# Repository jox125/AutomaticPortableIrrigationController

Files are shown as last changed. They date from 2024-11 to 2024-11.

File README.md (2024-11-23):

# Automatic Portable Irrigation System

This automatic watering system was developed and manufactured as my final thesis in Mechatronics at the Võru County Vocational Education Center.
In this repository you find two main parts: 
1. Water distribution system hardware overview
2. Controller software

All parts are placed in a common housing to ensure easy installation and transportation of the system.
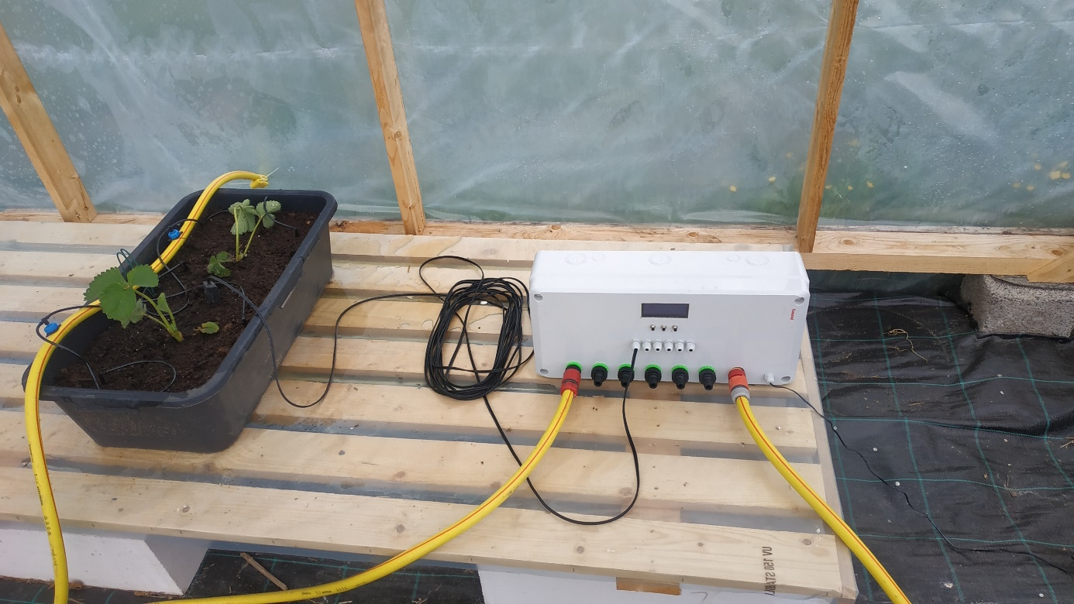
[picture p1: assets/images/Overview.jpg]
Overview of the system in testing

You can find additional information in my thesis in [here](/assets/Joel_Lepp_Thesis_est.docx)

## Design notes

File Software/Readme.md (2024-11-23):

This software is made for Arduino Mega 2560. 
This board was chosen with the possibility of adding future features in mind.

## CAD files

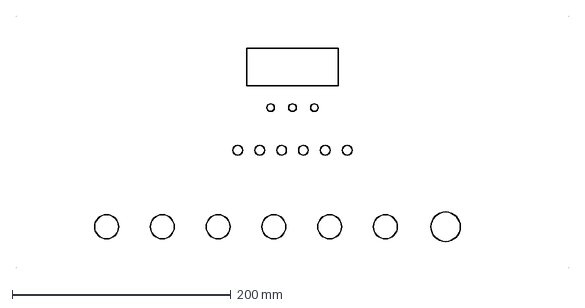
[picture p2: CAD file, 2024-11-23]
Hardware/Front panel.dxf
505.2 x 230.2 mm

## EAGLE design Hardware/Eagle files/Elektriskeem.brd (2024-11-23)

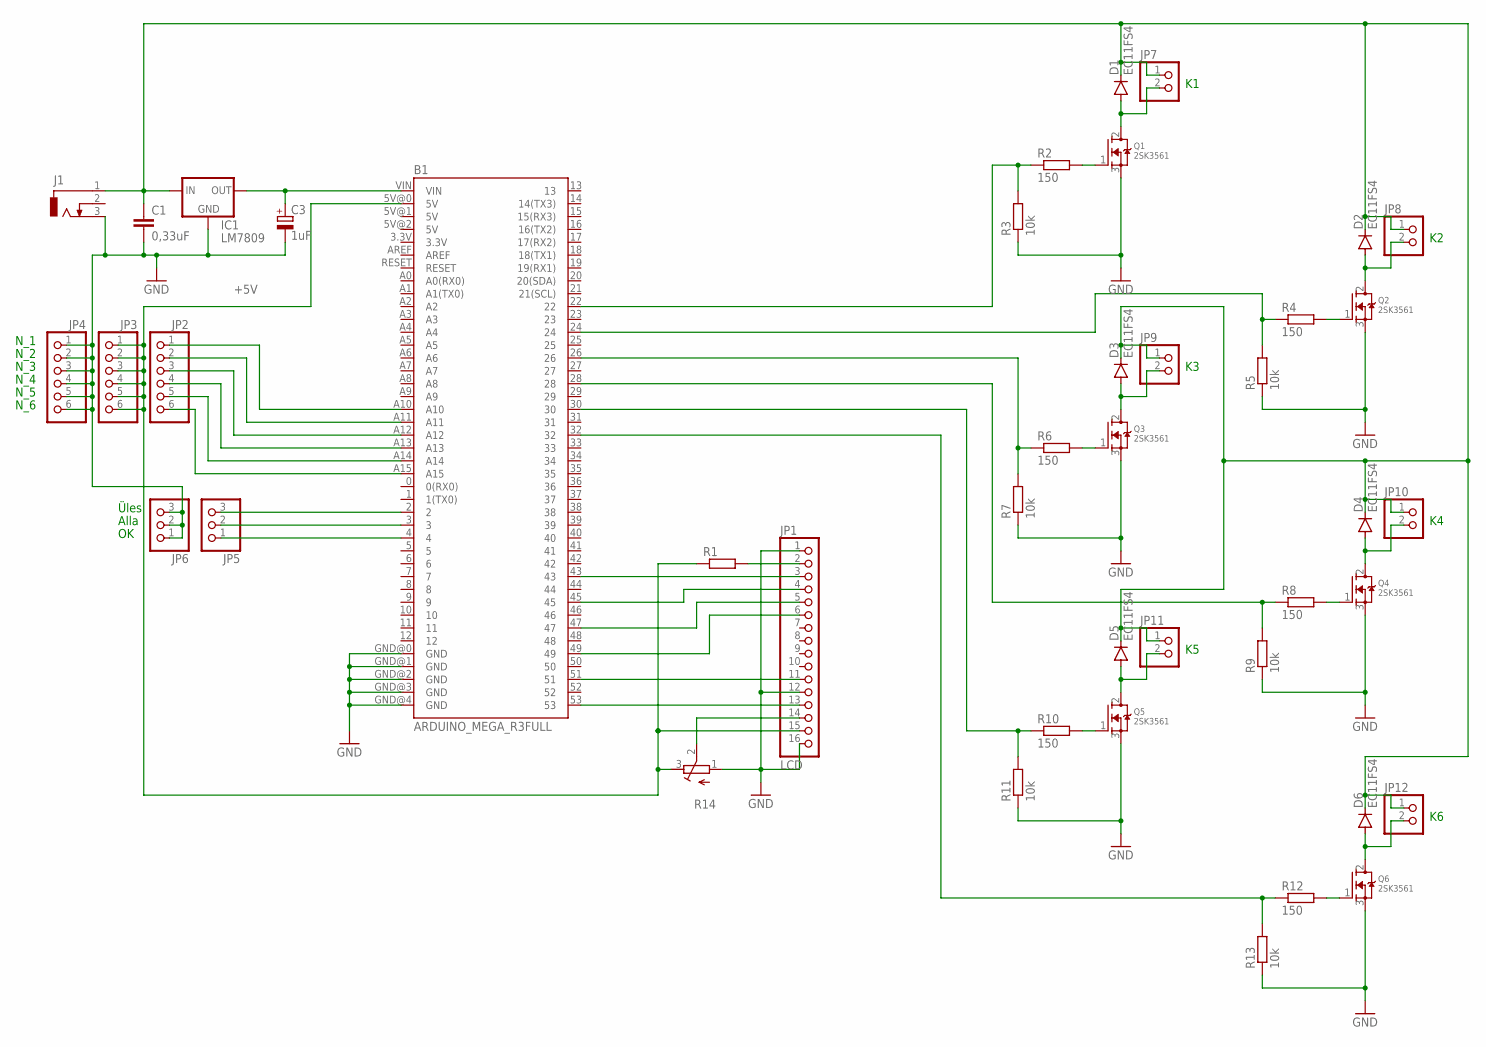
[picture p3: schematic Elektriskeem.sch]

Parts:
B1: ARDUINO_MEGA_R3FULL; ARDUINO_MEGA
C1: 0,33uF; C102-043X133
C3: 1uF; E2,5-6
D1, D2, D3, D4, D5, D6: EC11FS4; DO214AA
IC1: LM7809; 78XXS
J1: DCJ0303
JP1: LCD; 1X16
JP2, JP3, JP4: PINHD-1X6; 1X06
JP5, JP6: PINHD-1X3; 1X03
JP7, JP8, JP9, JP10, JP11, JP12: PINHD-1X2; 1X02
Q1, Q2, Q3, Q4, Q5, Q6: 2SK3561; TO220V
R1: R-EU_0207/12; 0207/12
R2, R4, R6, R8, R10, R12: 150; 0207/12
R3, R5, R7, R9, R11, R13: 10k; 0207/12
R14: R-TRIMM3339P; RTRIM3339P

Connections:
+5V: B1.5V@0 (5V), JP1.15, JP3.1, JP3.2, JP3.3, JP3.4, JP3.5, JP3.6, R1.1, R14.3 (E)
GND: B1.GND@0 (GND), B1.GND@1 (GND), B1.GND@2 (GND), B1.GND@3 (GND), B1.GND@4 (GND), C1.2, C3.-, IC1.GND, J1.3, JP1.1, JP1.12, JP1.16, JP4.1, JP4.2, JP4.3, JP4.4, JP4.5, JP4.6, JP6.1, JP6.2, JP6.3, Q1.3 (S), Q2.3 (S), Q3.3 (S), Q4.3 (S), Q5.3 (S), Q6.3 (S), R3.1, R5.1, R7.1, R9.1, R11.1, R13.1, R14.1 (A)
unnamed: C1.1, D1.C, D2.C, D3.C, D4.C, D5.C, D6.C, IC1.IN, J1.1, JP7.1, JP8.1, JP9.1, JP10.1, JP11.1, JP12.1
unnamed: B1.2, JP5.3
unnamed: B1.VIN, C3.+, IC1.OUT
unnamed: B1.A15, JP2.6
unnamed: B1.26, R6.1, R7.2
unnamed: B1.A14, JP2.5
unnamed: B1.A13, JP2.4
unnamed: B1.A12, JP2.3
unnamed: B1.A11, JP2.2
unnamed: B1.A10, JP2.1
unnamed: B1.43, JP1.3
unnamed: B1.53, JP1.13
unnamed: JP1.2, R1.2
unnamed: JP1.14, R14.2 (S)
unnamed: B1.51, JP1.11
unnamed: B1.45, JP1.4
unnamed: B1.47, JP1.5
unnamed: B1.49, JP1.6
unnamed: B1.3, JP5.2
unnamed: B1.4, JP5.1
unnamed: Q1.1 (G), R2.2
unnamed: D1.A, JP7.2, Q1.2 (D)
unnamed: B1.22, R2.1, R3.2
unnamed: D3.A, JP9.2, Q3.2 (D)
unnamed: Q3.1 (G), R6.2
unnamed: D5.A, JP11.2, Q5.2 (D)
unnamed: Q5.1 (G), R10.2
unnamed: B1.30, R10.1, R11.2
unnamed: D2.A, JP8.2, Q2.2 (D)
unnamed: Q2.1 (G), R4.2
unnamed: B1.24, R4.1, R5.2
unnamed: D4.A, JP10.2, Q4.2 (D)
unnamed: Q4.1 (G), R8.2
unnamed: B1.28, R8.1, R9.2
unnamed: D6.A, JP12.2, Q6.2 (D)
unnamed: Q6.1 (G), R12.2
unnamed: B1.32, R12.1, R13.2

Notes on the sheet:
Üles
Alla
N_1
N_2
N_3
N_4
N_5
N_6

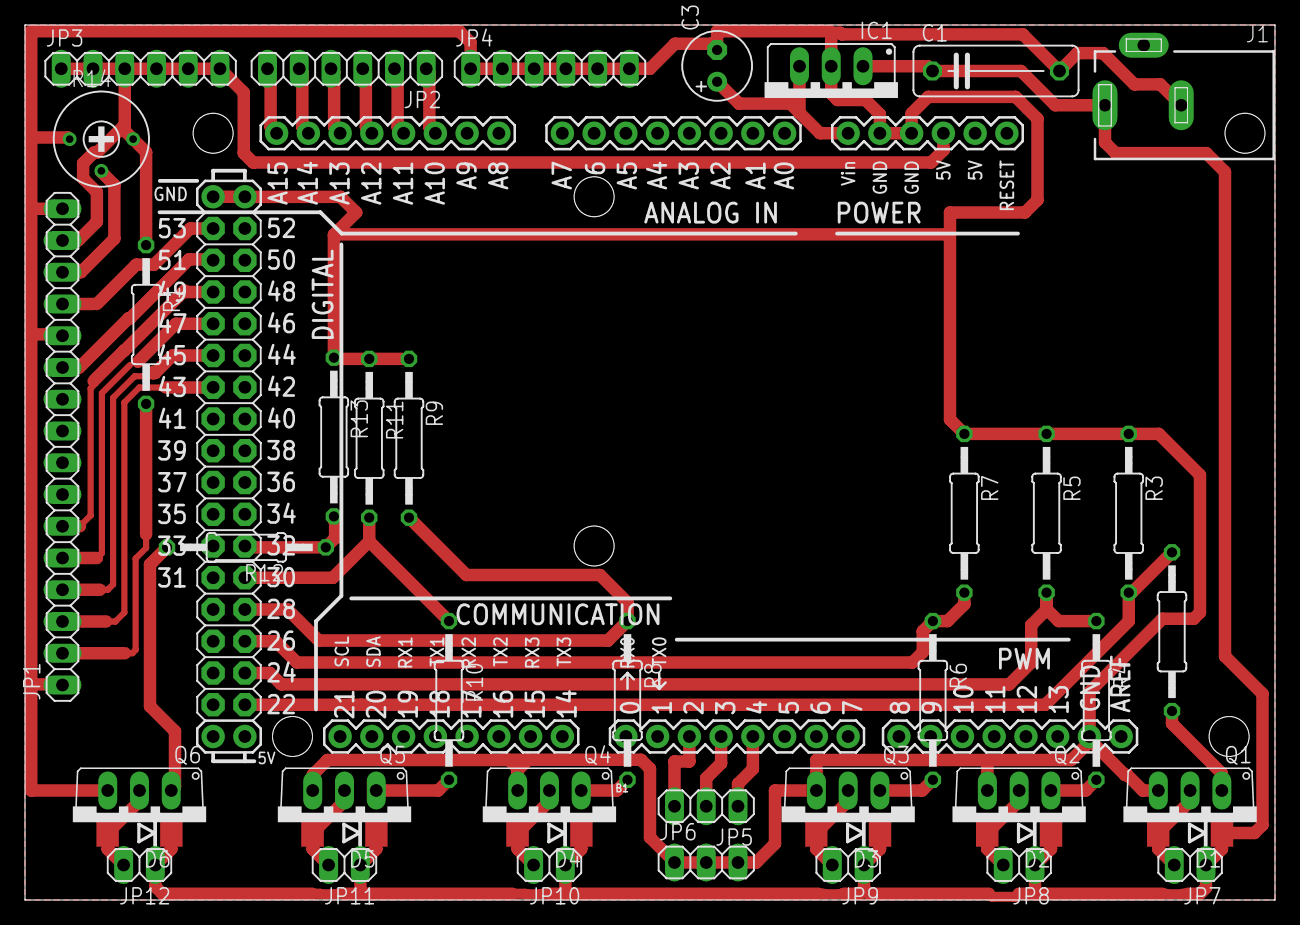
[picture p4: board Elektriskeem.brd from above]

Board: 2 copper layers, 100.0 x 70.0 mm, 43 parts (0 on the bottom side), 39 nets.

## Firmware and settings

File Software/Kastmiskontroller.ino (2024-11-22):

//*********************************************//
//*            LCD seadistus                  *//
//*********************************************//

//Lisa LCD teek.
#include <LiquidCrystal.h>

//seadista LiquidCrystal teek
const int rs = 53, en = 51, d4 = 49, d5 = 47, d6 = 45, d7 = 43;
LiquidCrystal lcd(rs, en, d4, d5, d6, d7);

//Ajaviideteks vajalikud muutujad
// Ekraani taimeri eelmine salvestatud aeg
unsigned long ekraan_eelmineMillis = 0;
// Ekraani värskendamise intervall millisekundites (sek x 1000)
unsigned long ekraan_intervall = 500; //0,5 sek

//*********************************************//
//*            Nuppude seadistus              *//
//*********************************************//

//Lisa Nuppude teek.
#include <Button.h>
//seadista nuppude pin-id.
Button ules_nupp(2); //üles nupp ühendatud D2 ja GND vahele
Button alla_nupp(3); //alla nupp ühendatud D3 ja GND vahele
Button ok_nupp(4);   //ok nupp ühendatud D4 ja GND vahele
//Ajaviideteks vajalikud muutujad
// Nuppude taimeri eelmine salvestatud aeg
unsigned long ules_nupp_eelmineMillis = 0;
unsigned long alla_nupp_eelmineMillis = 0;
// nuppuvajutuste intervall millisekundites (sek x 1000)
unsigned long nupud_intervall = 1000; //1 sek

int arv = 0;
bool alla_nupp_vajutatud = false;
bool ules_nupp_vajutatud = false;

//*********************************************//
//*    Globaalsete muutujate deklareerimine   *//
//*********************************************//

//Niiskuse mõõtmiseks vajalikud muutujad

//Mõõdetud niiskus 
int niiskused[6] = {100,100,100,100,100,100};
int min_niiskus = 910;
int max_niiskus = 510;
//Vajalikud analoog sisendid
int N_andur [6] = {10,11,12,13,14,15};  //Niiskuse andurite pin-id A10-A15 
//Ajaviideteks vajalikud muutujad
// Niiskuse taimeri eelmine salvestatud aeg
unsigned long niiskus_eelmineMillis = 0;
// Niiskuse mõõtmise intervall millisekundites (sek x 1000)
unsigned long niiskus_intervall = 10000; //10 sek

//Kastmise alamprogrammi muutujad

//toimub kastmine bit
bool toimub_kastmine [6] = {false, false, false, false, false, false}; 
//releede pin-ide määramine
int releed [6] = {22,24,26,28,30,32}; //releede pin-id D22 - D32
//mulla niiskuse protsent, millest kuivema mulla korral hakatakse kastma
//ja millest niiskema mulla korral lõpetatakse kastmine
int min_niiskus_s2te [6] = {0,0,0,0,0,0}; 
int max_niiskus_s2te [6] = {90,90,90,90,90,90}; 
//Ajaviideteks vajalikud muutujad
// Kastmise alamprogrammi taimeri eelmine salvestatud aeg
unsigned long kastmine_eelmineMillis = 0;
//kastmise alamprogrammi intervall millisekundites (sek x 1000)
unsigned long kastmine_intervall = 1000; //1 sek

//kontroll alamprogrammi globaalsed muutujad.
int aktiivne_ekraan = 0;
int grupp = 1; //hetkel aktiivne grupp, mille seadeid muudetakse

void setup() {
//setup käsud täidetakse üks kord arduino käivitumisel
//Serial.begin(9600);

//Seadista nupud
ules_nupp.begin(); //käivita üles nupp jälgimine 
alla_nupp.begin(); //käivita alla nupp jälgimine
ok_nupp.begin();   //käivita ok nupp jälgimine

//Seadista LCD sümbolite arv ja read
  lcd.begin(20, 4);
  // Print a message to the LCD.
  lcd.print("Kastmis kontroll");
  delay (2000);
  lcd.clear();

//releede pin-ide konfigureerimine
for (int a=0; a<6; a++){
  pinMode(releed [a], OUTPUT);
  }
}

void loop() {
  // Programmi tsükliline osa
niiskus ();
kastmine ();
kontroll ();
}


void niiskus (){
/*
 * Niiskuse mõõtmine. Mõõdab iga määratud T_niiskus (ms) järel
 * gruppide kaupa mulla niiskuse ja salvestab tulemuse niiskused massiivi. 
 */  
  unsigned long hetkeMillis = millis();
  //aja intervalli möödumise kontroll 
  if(hetkeMillis - niiskus_eelmineMillis > niiskus_intervall) {
    niiskus_eelmineMillis = hetkeMillis;
    //kõik grupid 
    //Serial.print("Mulla niiskused: ");  
    for (int i = 0; i<6; i++){
      //kümne mõõtmise keskmine
      int keskmine = 0;
      for (int e=0; e<10; e++){
        keskmine = keskmine + analogRead(N_andur[i]);
        }
      keskmine = keskmine / 10;
      //mõõdetud niiskuse salvestamine massiivi
      niiskused [i] = map(keskmine, min_niiskus, max_niiskus, 0, 100);
      //Serial.print(niiskused[i]);
      //Serial.print(" ; ");
      }
      //Serial.println();
    }
    
}
void kastmine (){
/*
 * Kui eelmisest programmi käivitamisest on möödunud piisavalt aega, siis 
 * gruppide kaupa kontrollib, kui kastmist ei toimu, siis kui niiskus on 
 * allpool määratud piiri, kastmine sisse, kastmine bit tõeseks.   
 * Kui kastmine toimub, siis kui muld on piisavalt märg
 * kastmine välja, kastmine bit vääraks.
 */
unsigned long hetkeMillis = millis();
  //aja intervalli möödumise kontroll 
  if (hetkeMillis - kastmine_eelmineMillis > kastmine_intervall) {
    kastmine_eelmineMillis = hetkeMillis;
    //kõik grupid 
    //Serial.print("Kastmised: ");  
    for (int i = 0; i<6; i++){
      if (!toimub_kastmine[i]){ //kas ei toimu juba antud grupi kastmine
        if(niiskused[i]<min_niiskus_s2te[i]){ //kas mulla niiskus on väiksem etteantud min. sättest
          digitalWrite (releed[i], HIGH); //antud grupi kastmine sisse (relee blokkil led kustu)
          toimub_kastmine[i] = true; //antud grupi kastmine toimub bit tõeseks
          }        
        }
        else if (niiskused[i]>max_niiskus_s2te[i]){//kui toimub juba antud grupi kastmine ja 
                                                //muld on juba piisavalt märg, siis
          digitalWrite (releed[i], LOW); //antud grupi kastmine välja (relee blokkil led sees)
          toimub_kastmine[i] = false; //antud grupi kastmine toimub bit vääraks
          }
 
      //Serial.print(toimub_kastmine[i]);
      //Serial.print(" ; ");
      }
      //Serial.println();
    }
}

void kontroll (){
/*
 * Käivitab vastavalt selle ekraani alamprogrammi, milline on 
 * aktiivne_ekraan muutujaga aktiivseks määratud
 */
switch (aktiivne_ekraan){
  case 0: //avaekraan
    avaekraan();
    break;
  case 1: //avaekraan 2
    ekraan_2();
    break;     
  case 2: //gruppide seadistuse vaatamine
    Gruppide_seaded();
    break;
  case 3: //min niiskuse seadistus
    Min_seade_muutmine();
    break;
  case 4: //max niiskuse seadistus
    Max_seade_muutmine();
    break;
  default:
    avaekraan();
    break;
  }
}


void avaekraan (){
/*
 * nupu vajutuste kontroll ja alamprogrammide käivitamine
 * ekraani värskendus ettemääratud intervalliga
 */
  if (ules_nupp.pressed()||alla_nupp.pressed()){
    aktiivne_ekraan = 1; //ekraan_2
    }
  if (ok_nupp.pressed()){
    aktiivne_ekraan = 2; //Gruppide seade ekraan
    }
//aja intervalli möödumise kontroll ja ekraani värskendamine 
  unsigned long hetkeMillis = millis();
  if(hetkeMillis - ekraan_eelmineMillis > ekraan_intervall) {
    ekraan_eelmineMillis = hetkeMillis;
  lcd.clear();
  //LCD rida 1.
  lcd.setCursor(0, 0);
  lcd.print("HETKE NIISKUSED:");
  //LCD rida 2: niiskused gruppides 1 ja 2
  for (int i=0; i<2; i++){
      lcd.setCursor(i*10, 1);
      lcd.print("Gr.");
      lcd.print(i+1);
      lcd.print(":");
      lcd.print(niiskused[i]);
      lcd.print("%");
    }
  //LCD rida 3: niiskused gruppides 3 ja 4
  for (int i=2; i<4; i++){
      lcd.setCursor((i-2)*10, 2);
      lcd.print("Gr.");
      lcd.print(i+1);
      lcd.print(":");
      lcd.print(niiskused[i]);
      lcd.print("%");
    } 
  //LCD rida 4: niiskused gruppides 5 ja 6
  for (int i=4; i<6; i++){
      lcd.setCursor((i-4)*10, 3);
      lcd.print("Gr.");
      lcd.print(i+1);
      lcd.print(":");
      lcd.print(niiskused[i]);
      lcd.print("%");
    }    
  }
}

void ekraan_2 (){
/*
 * nupu vajutuste kontroll ja vastavalt aktiivse ekraani määramine
 * ekraani värskendus ettemääratud intervalliga
 * ekraanil ridade kaupa kuvada gruppide kastmine, mitte kastmine
 */
  if (ules_nupp.pressed()||alla_nupp.pressed()){
    aktiivne_ekraan = 0; //avaekraan
    }
  if (ok_nupp.pressed()){
    aktiivne_ekraan = 2; //Gruppide seadete ekraan
    }
//aja intervalli möödumise kontroll ja ekraani värskendamine 
  unsigned long hetkeMillis = millis();
  if(hetkeMillis - ekraan_eelmineMillis > ekraan_intervall) {
    ekraan_eelmineMillis = hetkeMillis;
  lcd.clear();
  //LCD rida 1.
  lcd.setCursor(0, 0);
  lcd.print("KAS TOIMUB KASTMINE?");
  //LCD rida 2: niiskused gruppides 1 ja 2
  for (int i=0; i<2; i++){
      lcd.setCursor(i*10, 1);
      lcd.print("Gr.");
      lcd.print(i+1);
      lcd.print(":");
      if (toimub_kastmine[i]){
        lcd.print(" JAH");
        }
      else {
        lcd.print("  EI");
        }
    }
  //LCD rida 3: niiskused gruppides 3 ja 4
  for (int i=2; i<4; i++){
      lcd.setCursor((i-2)*10, 2);
      lcd.print("Gr.");
      lcd.print(i+1);
      lcd.print(":");
      if (toimub_kastmine[i]){
        lcd.print(" JAH");
        }
      else {
        lcd.print("  EI");
        }
    } 
  //LCD rida 4: niiskused gruppides 5 ja 6
  for (int i=4; i<6; i++){
      lcd.setCursor((i-4)*10, 3);
      lcd.print("Gr.");
      lcd.print(i+1);
      lcd.print(":");
      if (toimub_kastmine[i]){
        lcd.print(" JAH");
        }
      else {
        lcd.print("  EI");
        }
    }    
  }
}

  
void Gruppide_seaded (){
/*
 * nupu vajutuste kontroll ja aktiivsete ekraanide määramine
 * ekraani värskendus ettemääratud intervalliga
 */
  if (ok_nupp.pressed()){
    aktiivne_ekraan = 3; //min seade muutmis ekraan
    }
  if (ules_nupp.pressed()){//aktiivne Grupp järgmine
    if(grupp < 6){
      grupp++; 
      }
      else {
        grupp = 1; //esimesest grupist üles uuesti
        }  
    }
  if (alla_nupp.pressed()){
   if (grupp > 1){
      grupp--;
      }
      else{
        grupp = 6; //6 grupist alla uuesti
        }  
    }
    
//aja intervalli möödumise kontroll ja ekraani värskendamine 
  unsigned long hetkeMillis = millis();
  if(hetkeMillis - ekraan_eelmineMillis > ekraan_intervall) {
    ekraan_eelmineMillis = hetkeMillis;
  lcd.clear();
  //LCD rida 1.
  lcd.setCursor(0, 0);
  lcd.print("G");
  lcd.print(grupp);
  lcd.print(" KASTMISE SEADED:");
  //LCD rida 2: miinimum niiskuse säte
  lcd.setCursor(0, 1);
  lcd.print(" ALGUS: ");
  lcd.print(min_niiskus_s2te[grupp-1]);
  lcd.print("%");
  //LCD rida 3: maksimum niiskuse säte
  lcd.setCursor(0, 2);
  lcd.print("  LOPP: ");
  lcd.print(max_niiskus_s2te[grupp-1]); 
  lcd.print("%");
  //LCD rida 4: tühi rida
  lcd.setCursor(0, 3);
  } 
}

void Min_seade_muutmine(){
/*
 * nupu vajutuste kontroll, sätete muutmine ja aktiivsete ekraani määramine
 * ekraani värskendus ettemääratud intervalliga
 */
 unsigned long hetkeMillis = millis();

  if (ok_nupp.pressed()){
    lcd.noBlink(); //kursori vilkumine OFF
    aktiivne_ekraan = 4; //max seade muutmis ekraan 
    }
//Üles nupu vajutusel lisab aktiivse grupi min sättele 1, nupu hoidmisel lisab järjest rohkem 
  if (!ules_nupp_vajutatud && ules_nupp.pressed()){ //kui üles nupp vajutatud esimest korda
    min_niiskus_s2te[grupp-1] += 1; //lisab Min. niiskuse sättele +1 
    ules_nupp_vajutatud = true;
    
    }
  if (ules_nupp.released()){ //kui üles nupp vabastatud
      ules_nupp_vajutatud = false;
      arv = 0; // arvu väärtus tagasi 0-ks.
    }    
  if(hetkeMillis - ules_nupp_eelmineMillis > nupud_intervall) {
    ules_nupp_eelmineMillis = hetkeMillis;
    if (ules_nupp_vajutatud && ules_nupp.read() == Button :: PRESSED){ //kui nupp aja intervalli möödumisel ikka veel vajutatud
      arv += 1; //suurendab iga kord arvu 1 võrra
      min_niiskus_s2te[grupp-1] += arv; //lisab Min. niiskuse sättele arv väärtuse
     }
  }  
  
//Alla nupu vajutusel lisab min sättele -1, nupu hoidmisel lisab järjest vähem 
  if (!alla_nupp_vajutatud && alla_nupp.pressed()){ //kui alla nupp vajutatud esimest korda
    min_niiskus_s2te[grupp-1] -= 1; //lisab Min. niiskuse sättele -1 
    alla_nupp_vajutatud = true;
    
    }
  if (alla_nupp.released()){ //kui alla nupp vabastatud
      alla_nupp_vajutatud = false;
      arv = 0; // arvu väärtus tagasi 0-ks.
    }    
  if(hetkeMillis - alla_nupp_eelmineMillis > nupud_intervall) {
    alla_nupp_eelmineMillis = hetkeMillis;
    if (alla_nupp_vajutatud && alla_nupp.read() == Button :: PRESSED){ //kui nupp aja intervalli möödumisel ikka veel vajutatud
      arv += 1; //suurendab iga kord arvu 1 võrra
      min_niiskus_s2te[grupp-1] -= arv; //vähendab Min. niiskuse sättet arvu väärtuse võrra
     }
  }
    
//aja intervalli möödumise kontroll ja ekraani värskendamine 
  if(hetkeMillis - ekraan_eelmineMillis > ekraan_intervall) {
    ekraan_eelmineMillis = hetkeMillis;
  lcd.clear();
  //LCD rida 1.
  lcd.setCursor(0, 0);
  lcd.print("G");
  lcd.print(grupp);
  lcd.print(" KASTMISE SEADED:");
  //LCD rida 2: miinimum niiskuse säte
  lcd.setCursor(0, 1);
  lcd.print(" ALGUS: ");
  lcd.print(min_niiskus_s2te[grupp-1]);
  lcd.print("%");
  //LCD rida 3: maksimum niiskuse säte
  lcd.setCursor(0, 2);
  lcd.print("  LOPP: ");
  lcd.print(max_niiskus_s2te[grupp-1]); 
  lcd.print("%");
  //LCD rida 4: tühi rida
  lcd.setCursor(0, 3);

  //kursor teksti ALGUS ette vikuma
  lcd.setCursor(0,1);
  lcd.blink(); 
  } 
}

void Max_seade_muutmine(){
/*
 * nupu vajutuste kontroll, sätete muutmine ja aktiivsete ekraanide määramine
 * ekraani värskendus ettemääratud intervalliga
 */
 unsigned long hetkeMillis = millis();

  if (ok_nupp.pressed()){
    lcd.noBlink();
    aktiivne_ekraan = 0; //tagasi avaekraanile 
    }
//Üles nupu vajutusel lisab aktiivse gruppi max sättele 1, nupu hoidmisel lisab järjest rohkem 
  if (!ules_nupp_vajutatud && ules_nupp.pressed()){ //kui üles nupp vajutatud esimest korda
    max_niiskus_s2te[grupp-1] += 1; //lisab Max. niiskuse sättele +1 
    ules_nupp_vajutatud = true;
    
    }
  if (ules_nupp.released()){ //kui üles nupp vabastatud
      ules_nupp_vajutatud = false;
      arv = 0; // arvu väärtus tagasi 0-ks.
    }    
  if(hetkeMillis - ules_nupp_eelmineMillis > nupud_intervall) {
    ules_nupp_eelmineMillis = hetkeMillis;
    if (ules_nupp_vajutatud && ules_nupp.read() == Button :: PRESSED){ //kui nupp aja intervalli möödumisel ikka veel vajutatud
      arv += 1; //suurendab iga kord arvu 1 võrra
      max_niiskus_s2te[grupp-1] += arv; //lisab Max. niiskuse sättele arv väärtuse
     }
  }  
  
//Alla nupu vajutusel lisab aktiivse gruppi max sättele -1, nupu hoidmisel lisab järjest vähem 
  if (!alla_nupp_vajutatud && alla_nupp.pressed()){ //kui alla nupp vajutatud esimest korda
    max_niiskus_s2te[grupp-1] -= 1; //lisab Max. niiskuse sättele -1 
    alla_nupp_vajutatud = true;
    
    }
  if (alla_nupp.released()){ //kui alla nupp vabastatud
      alla_nupp_vajutatud = false;
      arv = 0; // arvu väärtus tagasi 0-ks.
    }    
  if(hetkeMillis - alla_nupp_eelmineMillis > nupud_intervall) {
    alla_nupp_eelmineMillis = hetkeMillis;
    if (alla_nupp_vajutatud && alla_nupp.read() == Button :: PRESSED){ //kui nupp aja intervalli möödumisel ikka veel vajutatud
      arv += 1; //suurendab iga kord arvu 1 võrra
      max_niiskus_s2te[grupp-1] -= arv; //vähendab Min. niiskuse sättet arvu väärtuse võrra
     }
  }
    
//aja intervalli möödumise kontroll ja ekraani värskendamine 
  if(hetkeMillis - ekraan_eelmineMillis > ekraan_intervall) {
    ekraan_eelmineMillis = hetkeMillis;
  lcd.clear();
  //LCD rida 1.
  lcd.setCursor(0, 0);
  lcd.print("G");
  lcd.print(grupp);
  lcd.print(" KASTMISE SEADED:");
  //LCD rida 2: miinimum niiskuse säte
  lcd.setCursor(0, 1);
  lcd.print(" ALGUS: ");
  lcd.print(min_niiskus_s2te[grupp-1]);
  lcd.print("%");
  //LCD rida 3: maksimum niiskuse säte
  lcd.setCursor(0, 2);
  lcd.print("  LOPP: ");
  lcd.print(max_niiskus_s2te[grupp-1]); 
  lcd.print("%");
  //LCD rida 4: tühi rida
  lcd.setCursor(0, 3);

  //kursor teksti LOPP ette vikuma
  lcd.setCursor(0,2);
  lcd.blink(); 
  } 
}

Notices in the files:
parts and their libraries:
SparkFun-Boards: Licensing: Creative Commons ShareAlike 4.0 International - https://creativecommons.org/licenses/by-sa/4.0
